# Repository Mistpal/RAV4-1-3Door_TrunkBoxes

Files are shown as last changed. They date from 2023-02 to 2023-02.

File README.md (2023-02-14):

# RAV4 3Door (I) - Trunk Box
Ящики "спокойствия" в багажник Toyota RAV4 3двери

## Материалы
На оба ящика хватит одного листа 2440х1220х6мм.
Я использовал лакированную фанеру толщиной 6мм. 
На такой толщине очень трудно точно засверлиться без кондукторов, поэтому в проекте присутствуют две модели кондукторов (konduktor_1.STEP и konduktor_2.STEP)
которые можно напечатать на 3D принтере. Нюанс заключается в реальной толщине фанеры, в моём случае толщина составила в среднем 6.15мм вместо 6.0мм
Поэтому кондукторы построены на эту ширину. Вам необходимо на месте замерить толщину фанеры и подправить 3D модели кондукторов перед печатью!

Основное сверло диаметром 1.7мм - необходимо для извлечения лишнего материала, перед закручиванием шурупов.
Иначе такая тонкая фанера обязательно лопнет или не обеспечит жёсткость конструкции.

Стягиваем панели между собой шурупами 2.5х25мм, также понадобится зенкер для утопления шляпок шурупов.
Для установки упоров использовал винты с потайной головкой М5х25мм.

На 3D моделях отмечены отверстия под все шурупы и винты.
После раскроя материала необходимо на месте внести поправки к расположению отверстий под М5 винты т.к. это всё таки древесина и точность реза не высока.
Если есть возможность нарезать всё на ЧПУ станке, то это будет лучший выбор!

После раскроя материала необходимо пильные грани защитить (поркасить).
Выполнить черновую сборку а на финальной сборке нанести сантехнический силикон (я использовал чёрного цвета) на стыкуемые грани.

В моём варианте один из ящиков не имеет перегородок и полки, т.к хранится там крупногабаритный багаж (кейс инструментов, компрессор и т.п).

Видео:

https://youtube.com/shorts/30_tSxJGyqw

https://youtube.com/shorts/z93eGED23Zs

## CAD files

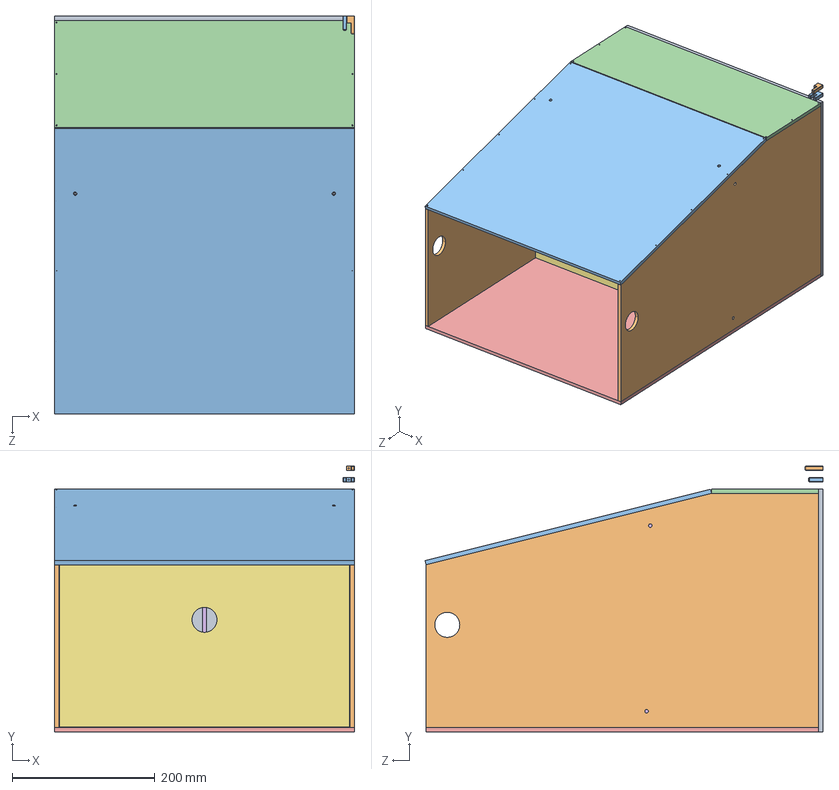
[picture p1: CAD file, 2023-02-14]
RAV4_TrunkBox.STEP
420.0 x 372.3 x 557.2 mm
SheetBottom
WallSide x 2
WallRearTop
WallRearBottom
WallFront
Septum x 3
Rack
Jamb x 2
Jamb2
Jamb2R
konduktor_1
konduktor_2
